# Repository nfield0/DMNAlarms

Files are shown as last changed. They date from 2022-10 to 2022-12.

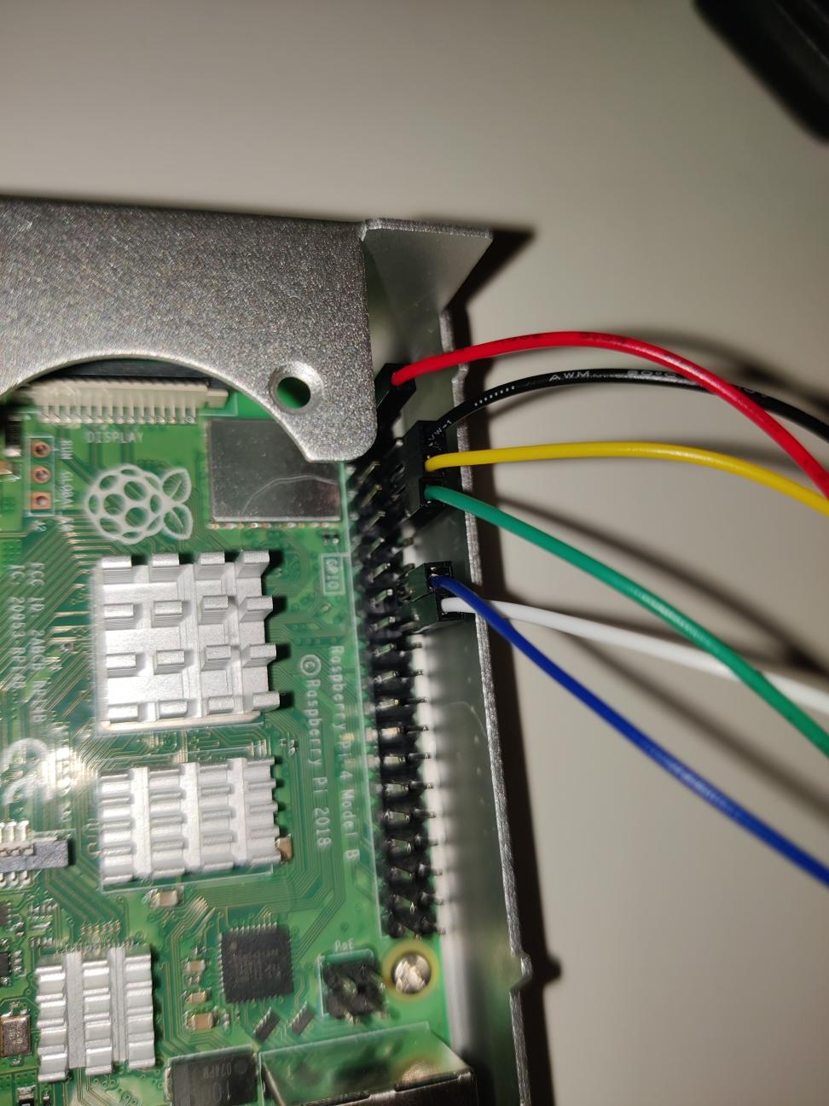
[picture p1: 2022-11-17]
correct_pi_connection_finger_scanner.jpg

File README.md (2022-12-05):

# TRIPL3F LTD
<p align="center">

</p>

## About Us
Our IoT application is an alarm system for single-entry rooms containing valuable documents of some form. After passing fingerprint and facial recognition, the electric strike door lock is unlocked, and entry is granted. There is a door sensor to detect when the door is open and closed. A Database is used to store fingerprint, facial images, date, and time of access. Each stage of the process is accompanied by a speaker, buzzer, and LCD display to guide the user through the system. A flask website is to be used to facilitate a typical front-end user.

### Team Members Roles:
David Campion: Frontend Developer<br />
Michael Flynn: Database Manager & Lead Tester <br />
Nathan Field: Backend Developer <br />
Nikita Fedans: Hardware + Architecture <br />

### Check Out our Website:
qr

shake-and-bake-ricky-bobby

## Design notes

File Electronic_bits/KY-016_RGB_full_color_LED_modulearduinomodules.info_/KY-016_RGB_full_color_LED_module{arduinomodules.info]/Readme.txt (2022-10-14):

//
// ARDUINOMODULES.INFO
// KY-016 RGB full color LED Module
//
// https://arduinomodules.info/ky-016-rgb-full-color-led-module/
//

File includes:
 |
 |- KY-016 RGB full color LED Module.fzpz		//Fritzing Custom Part
 |
 |- Readme.txt						//This file 

Changelog:
  
  Oct-2020
    -Fix Breadboard labels.
    -Fix Schematic labels.
    -Fix PCB holes.
    -Fix PCB size.
    -Fix copper layers order on PCB.

Disclaimer:

KY-016 RGB full color LED Module Fritzing Part is created by arduinomodules.info and published under Creative Commons Attribution-ShareAlike 4.0 International license (https://creativecommons.org/licenses/by-sa/4.0/).
You can use it, share it and/or modify it for any purposes as long as you distribute it under the same license and provide appropriate credit.

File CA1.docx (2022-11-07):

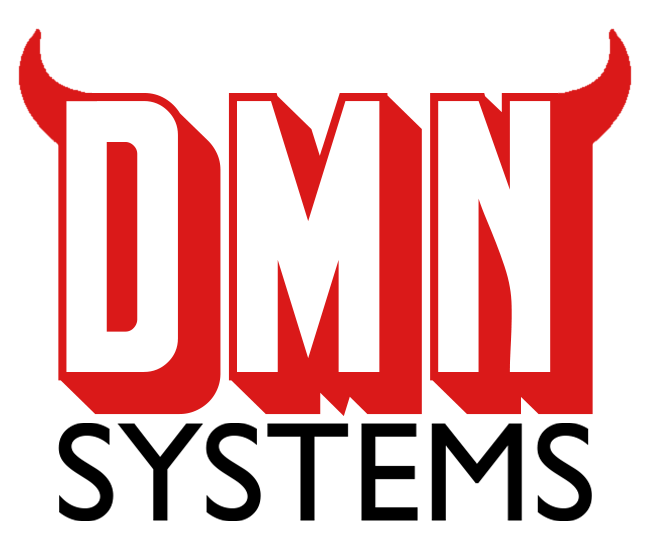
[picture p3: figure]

David Campion, Michael Flynn, Nathan Field & Nikita Fedans

A 2FA Security System for securing single-entry rooms

DMN sYSTEMS

DMN Alarms

DMN Alarms

David Campion, Michael Flynn, Nathan Field & Nikita Fedans

# Introduction

Our IoT application is an alarm system for single-entry rooms containing valuable documents of some form. After passing fingerprint and facial recognition, the electric strike door lock is unlocked, and entry is granted. There is a door sensor to detect when the door is open and closed. A Database is used to store fingerprint, facial images, date, and time of access. Each stage of the process is accompanied by a speaker, buzzer, and LCD display to guide the user through the system. A flask website is to be used to facilitate a typical front-end user.

Team Members Roles:

David Campion: Frontend + UX

Michael Flynn: Database + Testing

Nathan Field: Backend + Testing

Nikita Fedans: Backend + Architecture

# Hardware

## Circuit Diagrams

Circuit:

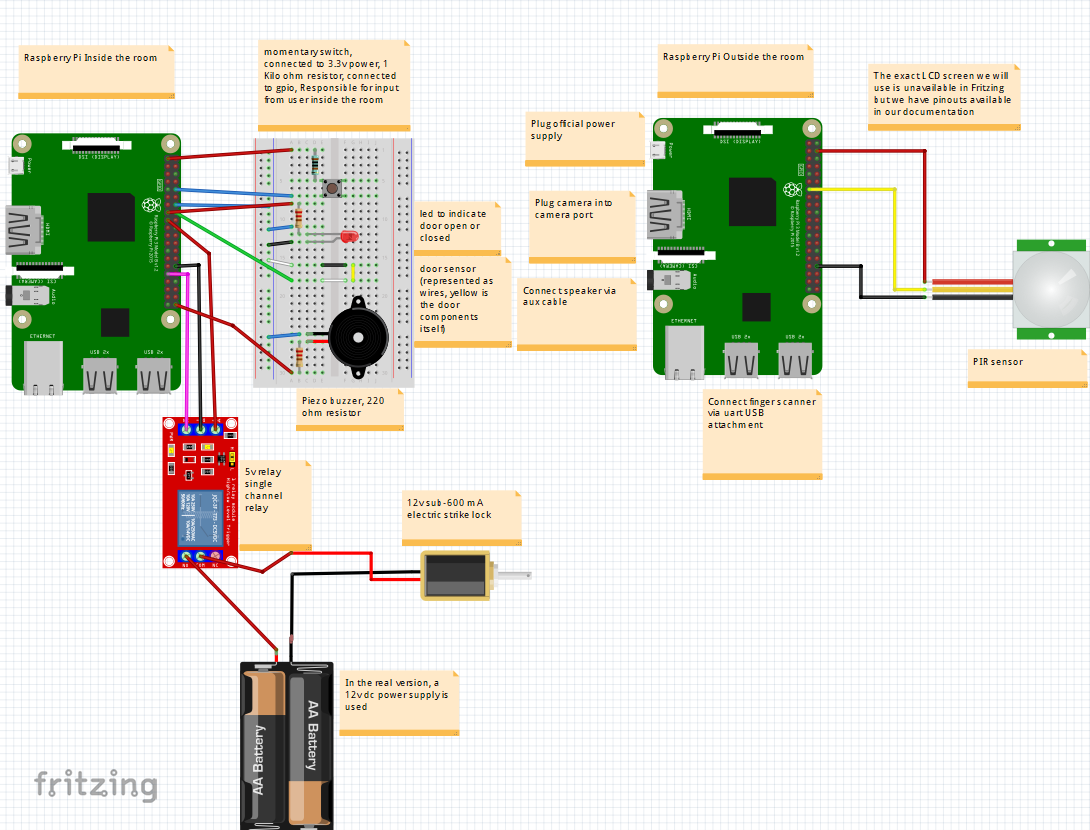
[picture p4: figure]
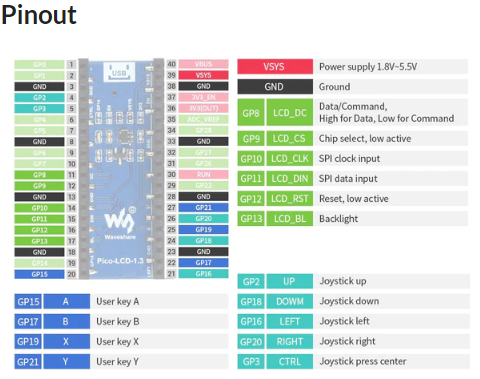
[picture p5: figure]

In Board mode:

Pin 39 of LCD display to Pin 1 of raspberry pi.

Pin 11,12,14,15,16 and 17 of LCD display to Pins 29,31,33,35,37,40 of raspberry pi.

Pin 20, 22, 25, 27 of LCD display to Pins 12, 16, 18 and 22 on raspberry pi.

Connect ground pins as required.

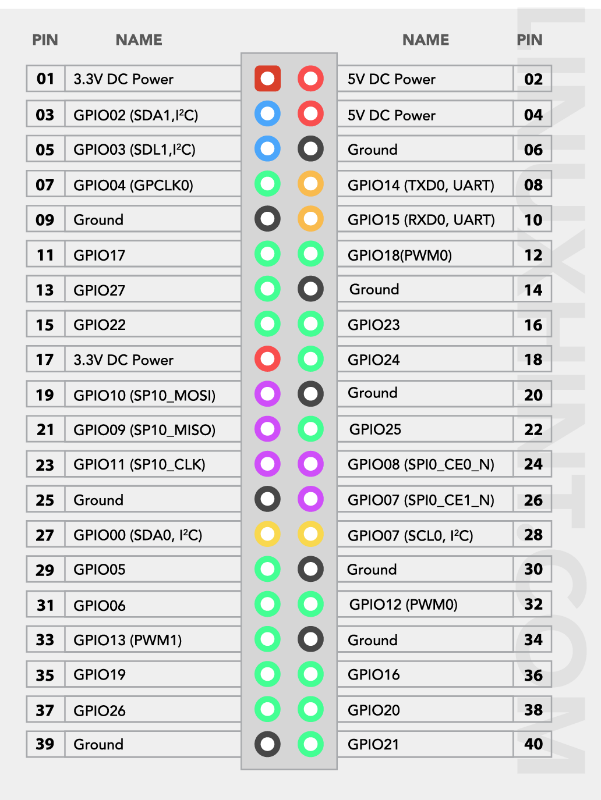
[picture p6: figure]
Raspberry Pi 4 GPIO Pinout

Fritzing circuit commentary:

- Raspberry pi 3 used for diagram. (4 was unavailable)
- Assuming LEDs need 2.2 forward voltage, the resistor needed is a 68.75 ohm one.
- The grounds of all the LEDs may be connected, and then plugged into a single ground pin on the pi, freeing up n-1 ground pins.
- Momentary switch button will be used for sending a signal to raspberry pi.
- No physical pull-down resistor is needed for the switch since an internal pull-down resistor may be assigned to a pin through code.
- LCD display requires a large number of wires and specific part was unavailable in fritzing.
- On the PIR sensor in the fritzing diagram, the VCC, OUT, and GND are inverted compared to the PIR sensors bought from www.pihut.com, so exercise caution when wiring the real thing.

Problems to solve:

- Research how to restrict the “Field of vision” of the pir sensor to only see a specific area.
- Build homemade door sensor.
- Cross-communication of 2 raspberry pi’s for each side of a doorway.

## Hardware Requirements:

Acquired:

1x pir sensor

1x pi camera module (specially made, plugs into special port)

1x buzzer (works with GPIO and 220-ohm resistor)

1x speaker (HDMX speaker, connected to aux, perhaps powered through USB)

Purchases required:

1x fingerprint sensor https://thepihut.com/products/round-all-in-one-capacitive-fingerprint-sensor-d?variant=41540357849283

1x USB to UART https://thepihut.com/products/usb-to-uart-module-micro-mini-type-a-or-type-c?variant=41771472584899

1x 1.3” IPS LCD Display https://thepihut.com/collections/raspberry-pi-screens/products/1-3-ips-lcd-display-module-for-raspberry-pi-pico-240x240

1x electric strike lock https://www.amazon.co.uk/gp/product/B0027VB810?psc=1

1x door switch (commercial or built)

1x button

# Security

## How to secure stored data

securely is one of the most crucial aspects of this project. As we are storing an individual’s personal information such as their name, fingerprint, and image, we must ensure that this sensitive information is therefore protected and not used in a malicious way.

### Securing the system

To ensure the employees personal information is protected we based our security measurements on the STRIDE threat model. The first threat we looked at was spoofing. One of the ways we try to combat spoofing is the user of our multi factor authentication system, this system prevents the user from gaining access to the door if they do not have the authorised fingerprint and facial recognition.

Tampering is another threat that could happen on both front and end, it is crucial to our system that there are different levels of access for each employee, i.e., an admin should be able to change code on the front end or backend, and a backend developer should not be able to add, edit or delete records from the database.

Repudiation was another issue that we were concerned with, if an unauthorised user got into the room and took sensitive documents’ they could deny taking them and we would have no proof to verify that they took it. We decided the best course of action would be to keep a log of which users accessed the room and at what time, this would be stored in a table in our database and will have a relationship with the employee table (employee to access one to many).

Next, we looked at how our system and database could prevent information from being leaked, i.e., how to stop people from finding our database name and password. Based off our lecturer’s guidance we decided to use env variables to prevent unauthorised access, this means that were we to send our code or push it to a site like GitHub then the aforementioned names and passwords will not be visible and there no information leak. We also hashed passwords for extra protection in the event of our database being breached.

Denial of Service attacks were a big worry for us, we therefore did extensive research on the ways in which to prevent these attacks from affecting us, with firewalls being the answer that appeared the most (VPNs and content filtering were other options in preventing these attacks.

In a recent article by Verizon, they claim that 80% of all data breaches happen due to compromised passwords. (https://www.verizon.com/business/resources/reports/dbir/), this worrying statistic got us thinking about how we can come up with more ways to stop users with access to the database and the admin section from having weak passwords, with the simplest solution being to make the user’s password to contain a special, uppercase, lowercase, and numerical character. We also looked at using multi-level authentication such as having a message being sent to your phone with a secure code like how companies such as Google and Amazon do it, however as our project is only small in size and we aren’t expecting attacks in this area, we decided that having a secure password will do for now.

### Privacy

Regarding privacy there was several laws and legislations that we had to consider. As we were using an individual’s personal information, we had to abide by GDPR and right to be forgotten law.

Firstly, will be looking at the GPDR and how we need to adhere to its 7 principles. Due to our usage of an employee’s personal information, it is crucial that we only use this information in a lawful, fair, and transparent manner. In essence we must be open and honest with our employees in how we are using their data as well as not use in inappropriate way such as sending it to third party companies (we are assuming they won’t consent to this)

Another way we must adhere to the GDPR is to only collect data of the employee that is necessary and relevant to what we will be using it for. So, for example we will only need the data such as name, fingerprint, and image and therefore we should be collecting information such as married status or something similar.

A final principle that I think we must adhere to in the GDPR is storage limitation. This law states that data should only be kept for as long as necessary. So, if an employee leaves the company in which the system is being implemented then they must be removed from the database as they information is no longer Is required.

This principle ties in with the second legislation we will be looking which is the Right to be forgotten Act. In essence this act allows a person to have their personal information removed from a company’s database or from the internet. It is important for us as a company to consider this act as if one of the employees leave our company and ask to be removed from the system we must do so.

## Physical security

Our System will have 2 raspberry pi’s mounted to a wall on both sides of the door.

Our Project will be able to control the locking mechanism of the door. In the event there was a power outage, or someone tried to tamper with the system by cutting the power to it, the door will remain locked when power is off. We considered the possibility of an emergency such as a fire, where any one inside may need to escape to safety. Considering this we considered using a backup power source for this project for emergency use only.

# Data Processing and Storage

In our project we will be making use of fingerprint scanners and facial recognition. These sensors will gather employees’ fingerprints and an image of their face, we will store this information in a database.

For our project we had to decide which database would be the most suitable, our options were the traditional MySQL or the more modern database Mongo DB. After careful consideration and deciding what data we will be storing, we opted with MySQL as our database as Mongo does not allow for relationships between the tables.

The first table in our database is the employee_table, in this table is where all the employees’ details such as their first name, surname, email and password as well as their fingerprint and image of their face for the facial recognition of the software, we will also include a Boolean for admin. For the two images the data type will be varchars however the images will be saved as a base64 encoder as it more efficient to transmit the images across the server. As well as this it will also give each employee a unique id to distinguish between each other, this id will function as the tables primary key(pk). Below is the schema and data types for the employee_table.

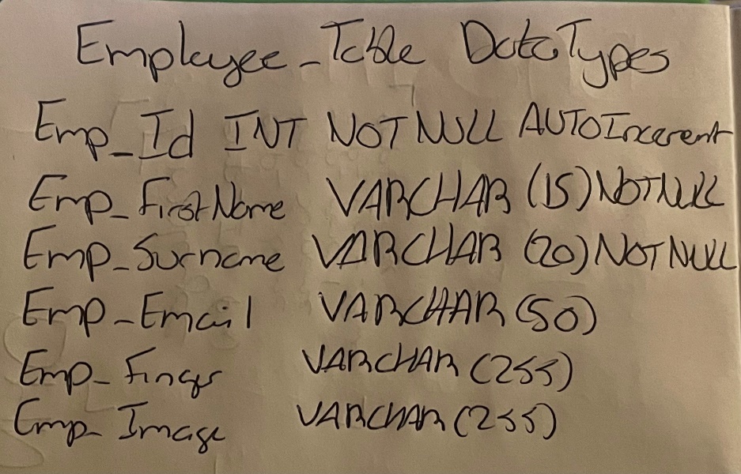
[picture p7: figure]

Theecondd table in our database is the employee_access_table, this table is used the monitor what employee is accessing the door and a what time they are accessed the door at. This table is a good way to improve the systems security and it limits the risk of repudiation (discussed in the security section of this documentation) as it means people can’t lie about whether they were or were not in the room. This table will contain a unique access id (pk) as well as the employees id (foreign key from the employee table) and an access time. Below is the schema for the employee_access_table

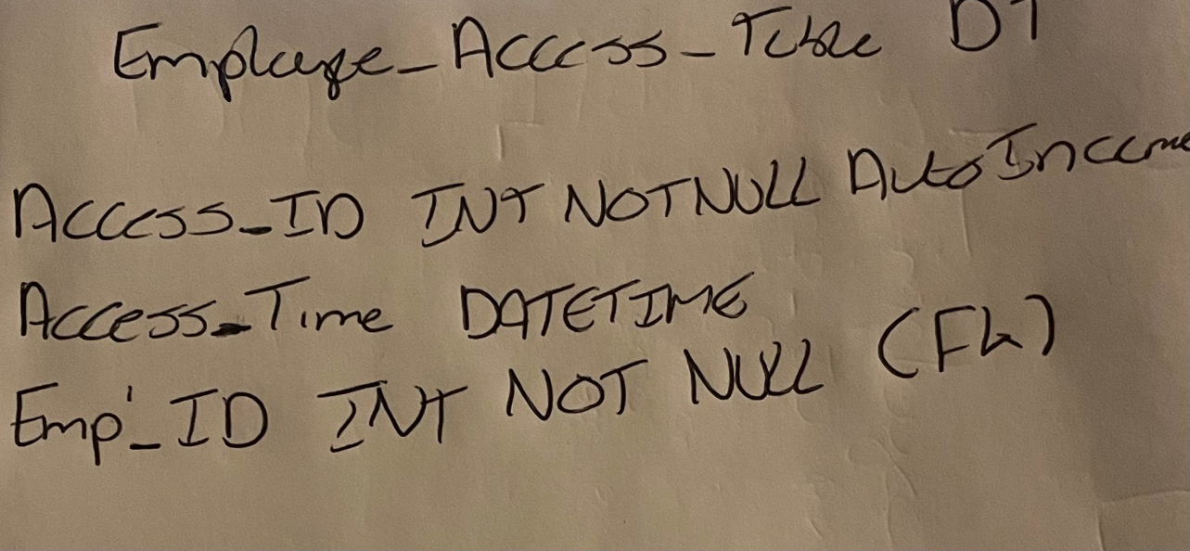
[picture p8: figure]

So as briefly mentioned we will be relating the two tables in our database, the relationship between these two tables is a one to many relationship (one employee can have many accesses to the door but the door can only have one access at any given time). Below is a sketch of the relationship between these two tables (note the admin Boolean is not in the diagram).

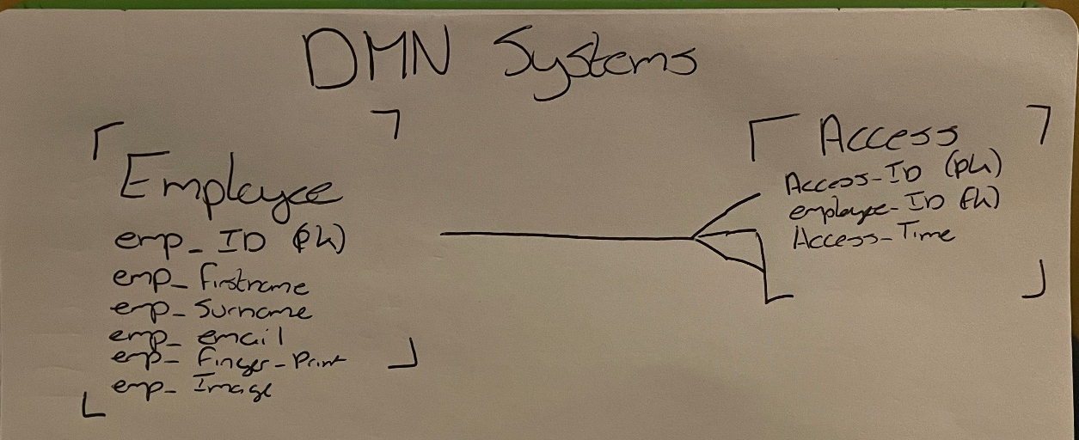
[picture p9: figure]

## Queries

We will also be using queries and views in our database to help us search for certain records in the database that combine both tables, while at the moment our queries are limited the plan is to expand on them as the database get bigger, below is our first few basic queries for the database

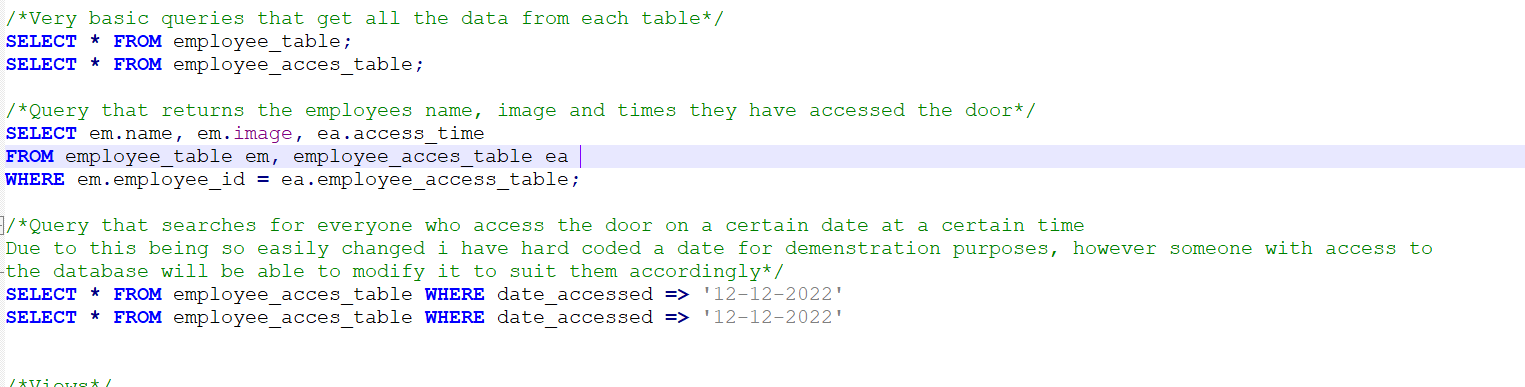
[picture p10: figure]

We will also be making use of views in our database to let other workers in the system search for certain records without risk of them editing or tampering with the records in anyway.

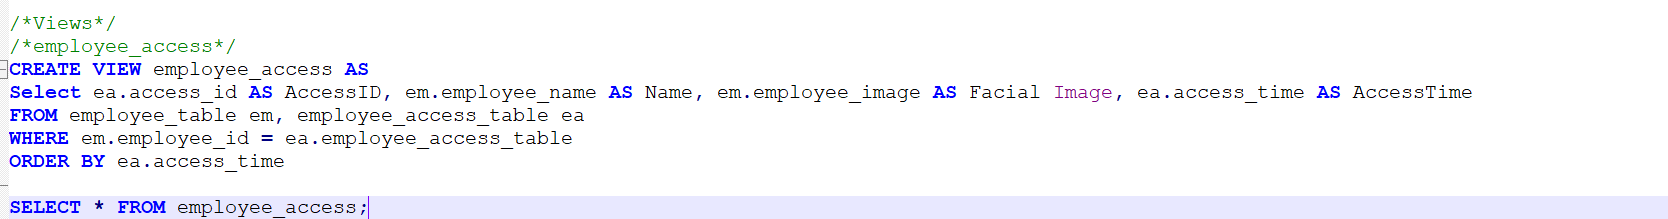
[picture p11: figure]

We also considered the possibility of using indexes for databases as well to allow our admins to quicky find employees by their last name. However, as our database is not the largest (yet) this index will probably not get much use as a simple SELECT emp_lastname FROM employee_table will get the results at the same speeds.

A final note on the database and something that will be discussed more in security, is securing the database to prevent it from hackers or SQL Injections. In order to prevent the latter, we will be making use of SQL parameters, these parameters will also hide the database structure from potential hackers. To do this in python you use connection.cursor(prepared = TRUE)

# The UI, User and User Testing

## The UI

(Provided by David Campion)

The Flask website design can be found here: https://www.figma.com/file/B5OAyUPiC5Eks1s3S356iJ/DMN-Systems-Prototype?node-id=0%3A1

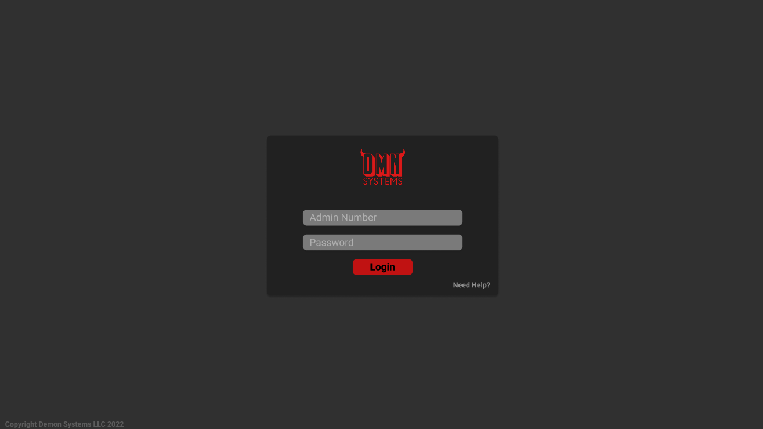
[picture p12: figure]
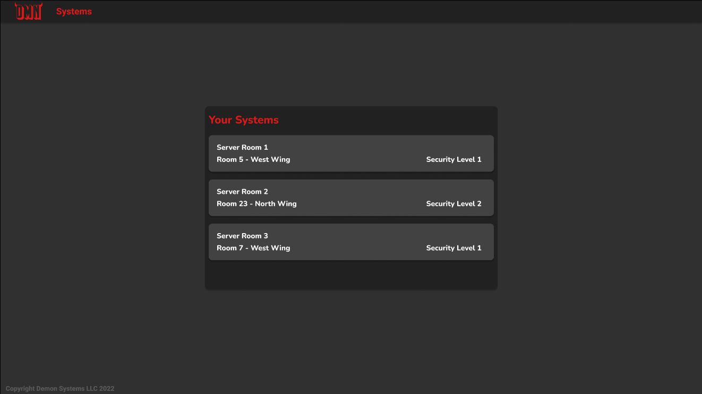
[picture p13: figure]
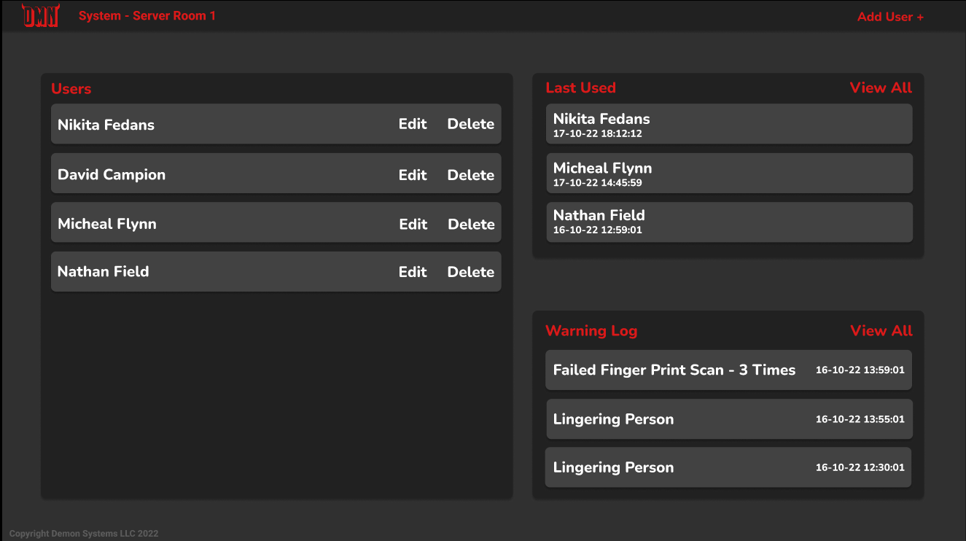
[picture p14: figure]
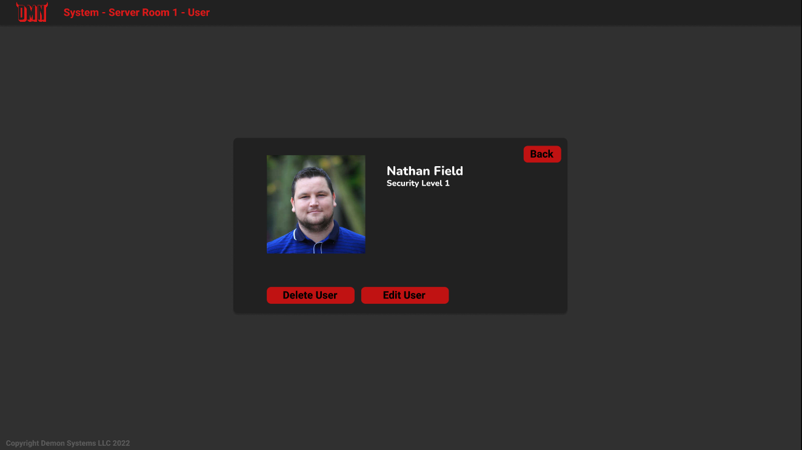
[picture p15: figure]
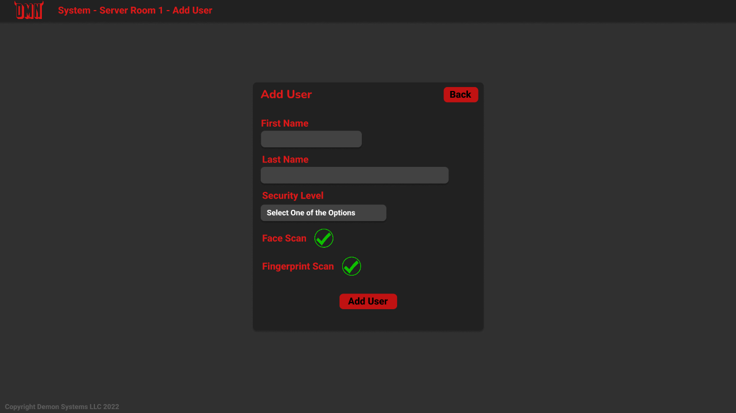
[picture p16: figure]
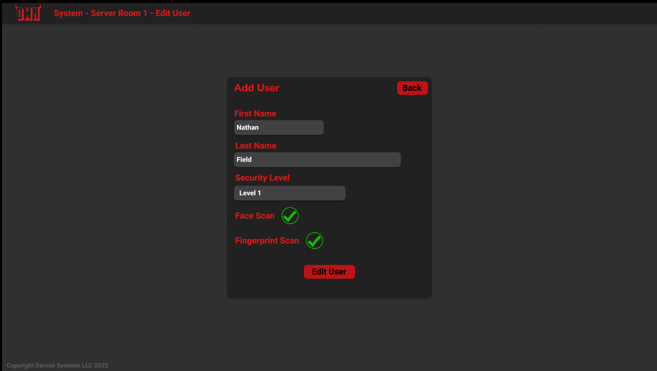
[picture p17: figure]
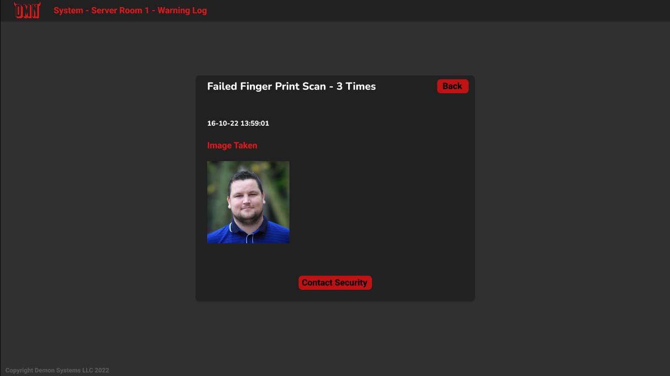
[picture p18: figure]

LCD display prototype here:

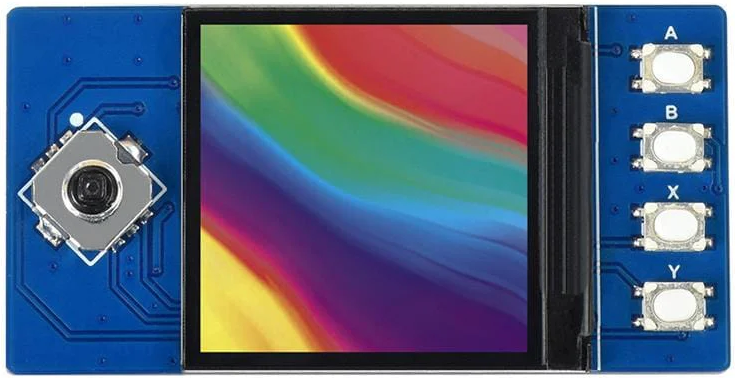
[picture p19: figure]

## The User

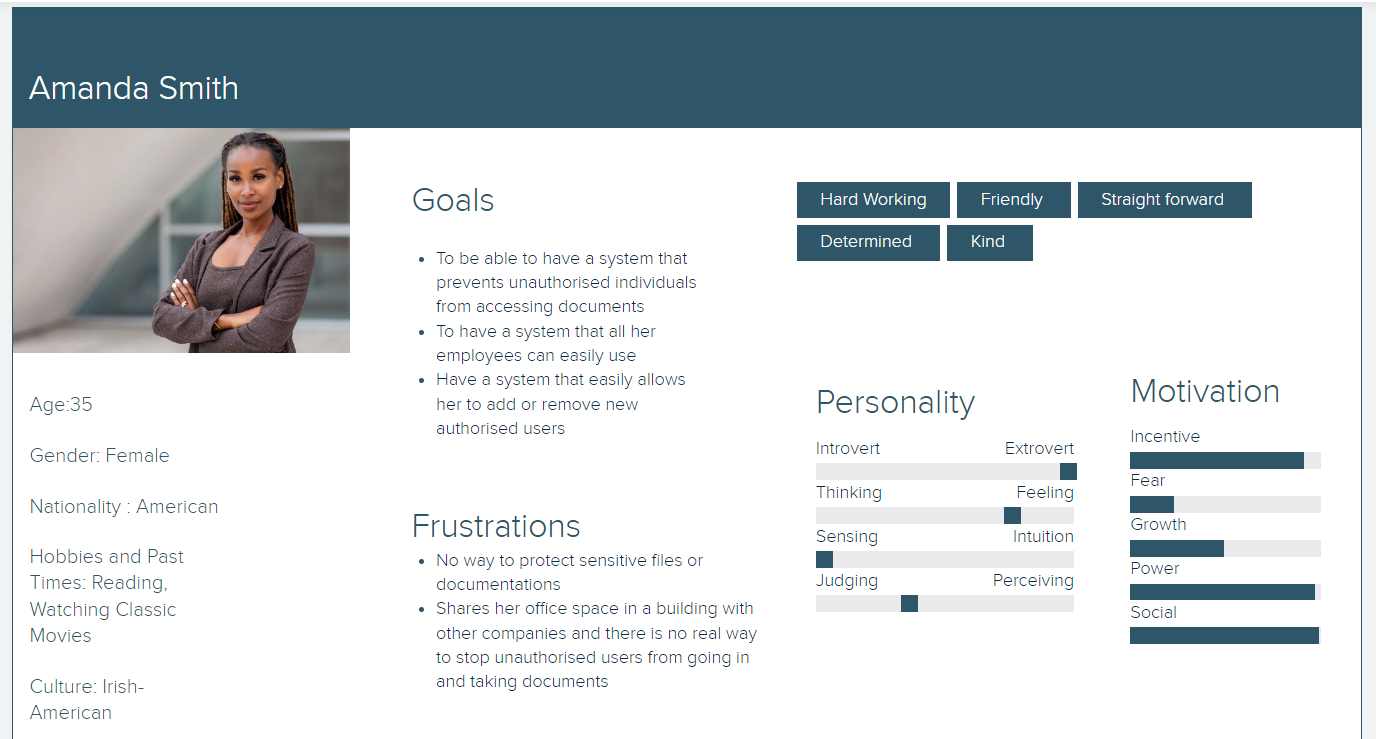
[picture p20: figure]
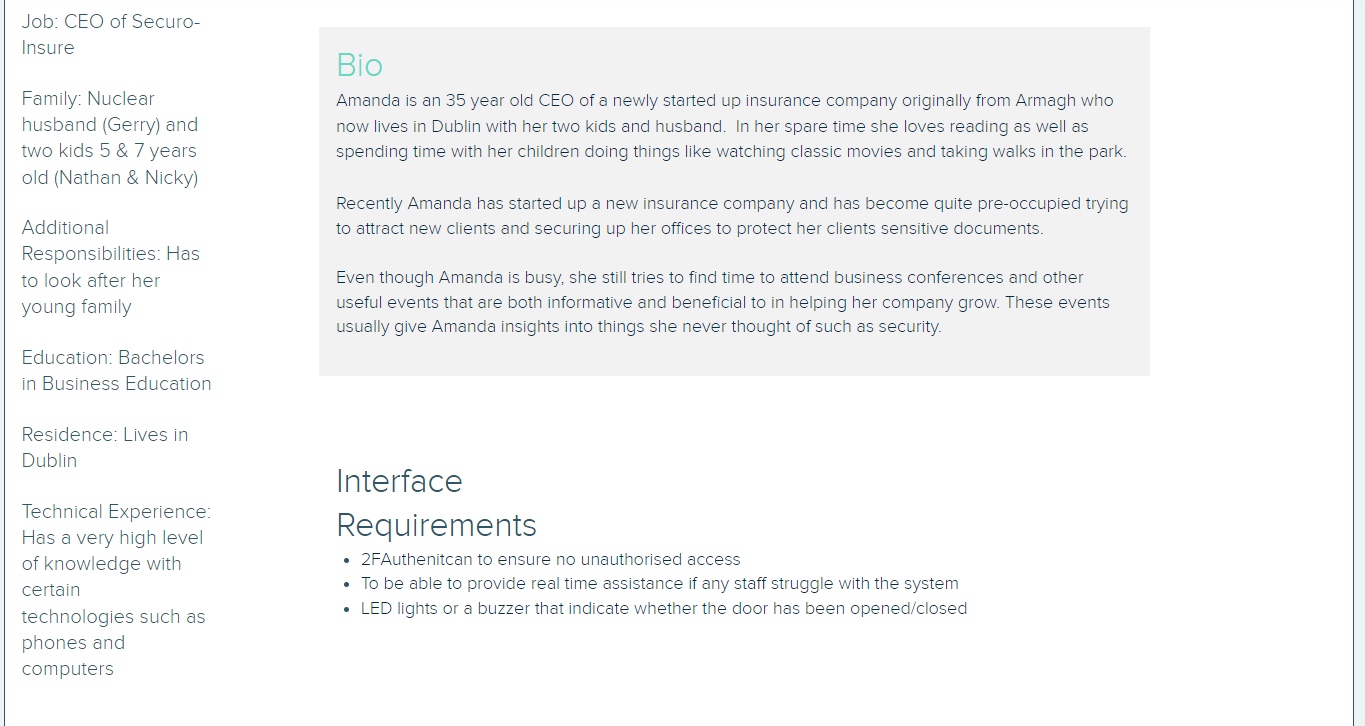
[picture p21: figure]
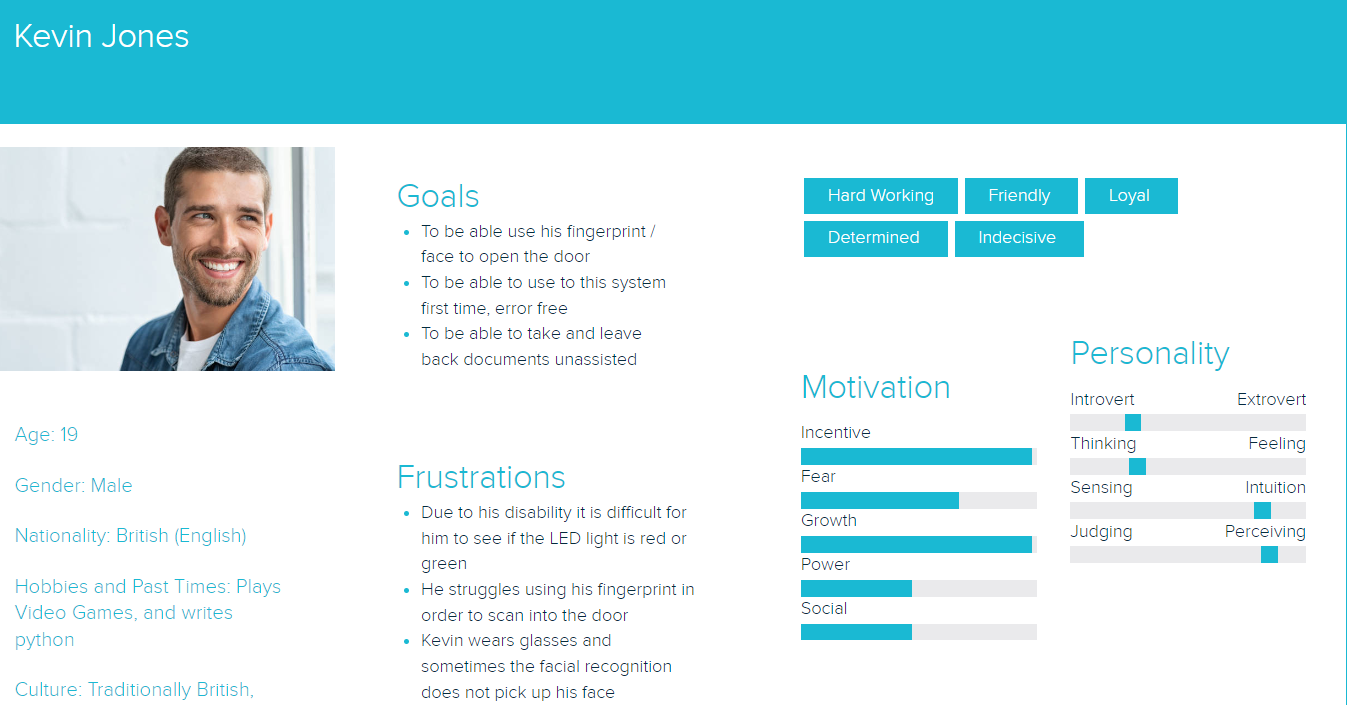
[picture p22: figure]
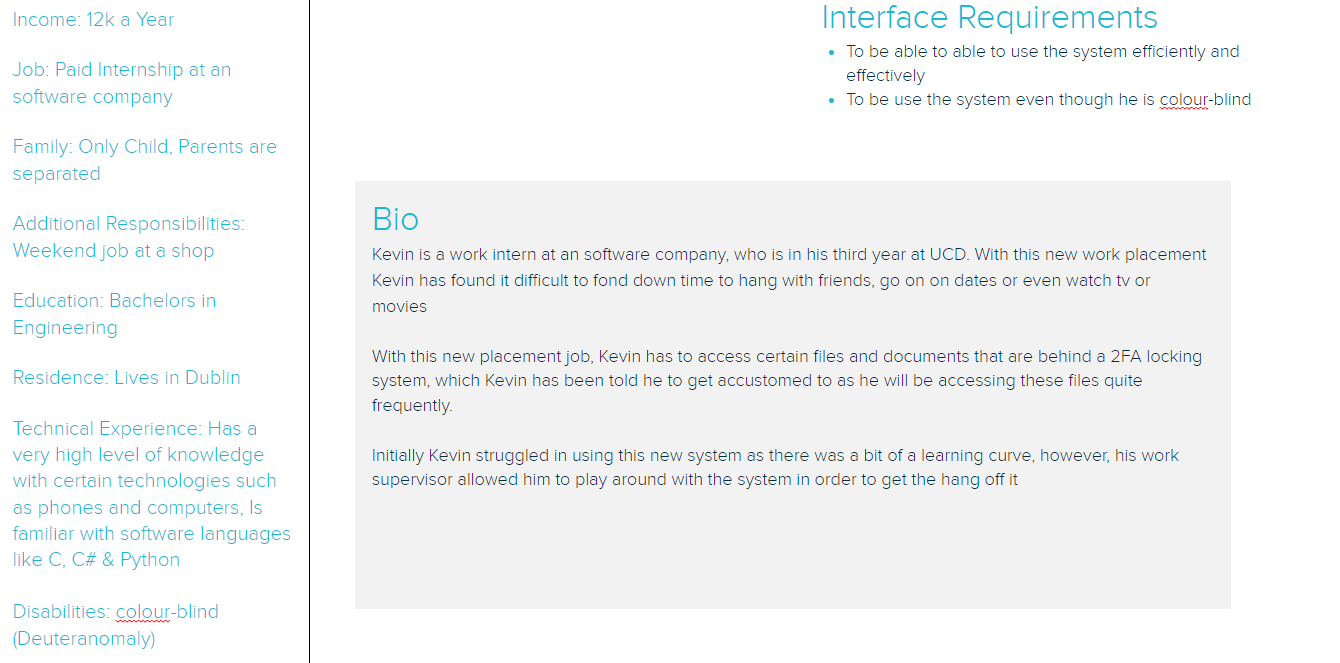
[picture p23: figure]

## User Testing

### User Interaction Flowcharts

1) Entering from the outside, available here: https://www.canva.com/design/DAFPBEU1cgY/_33aS6_us3ViciJL2B3JKQ/edit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
2) Exiting from the inside, available here: https://www.canva.com/design/DAFPB6XopUE/RulFr5eydPou51SDKPa_SQ/edit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

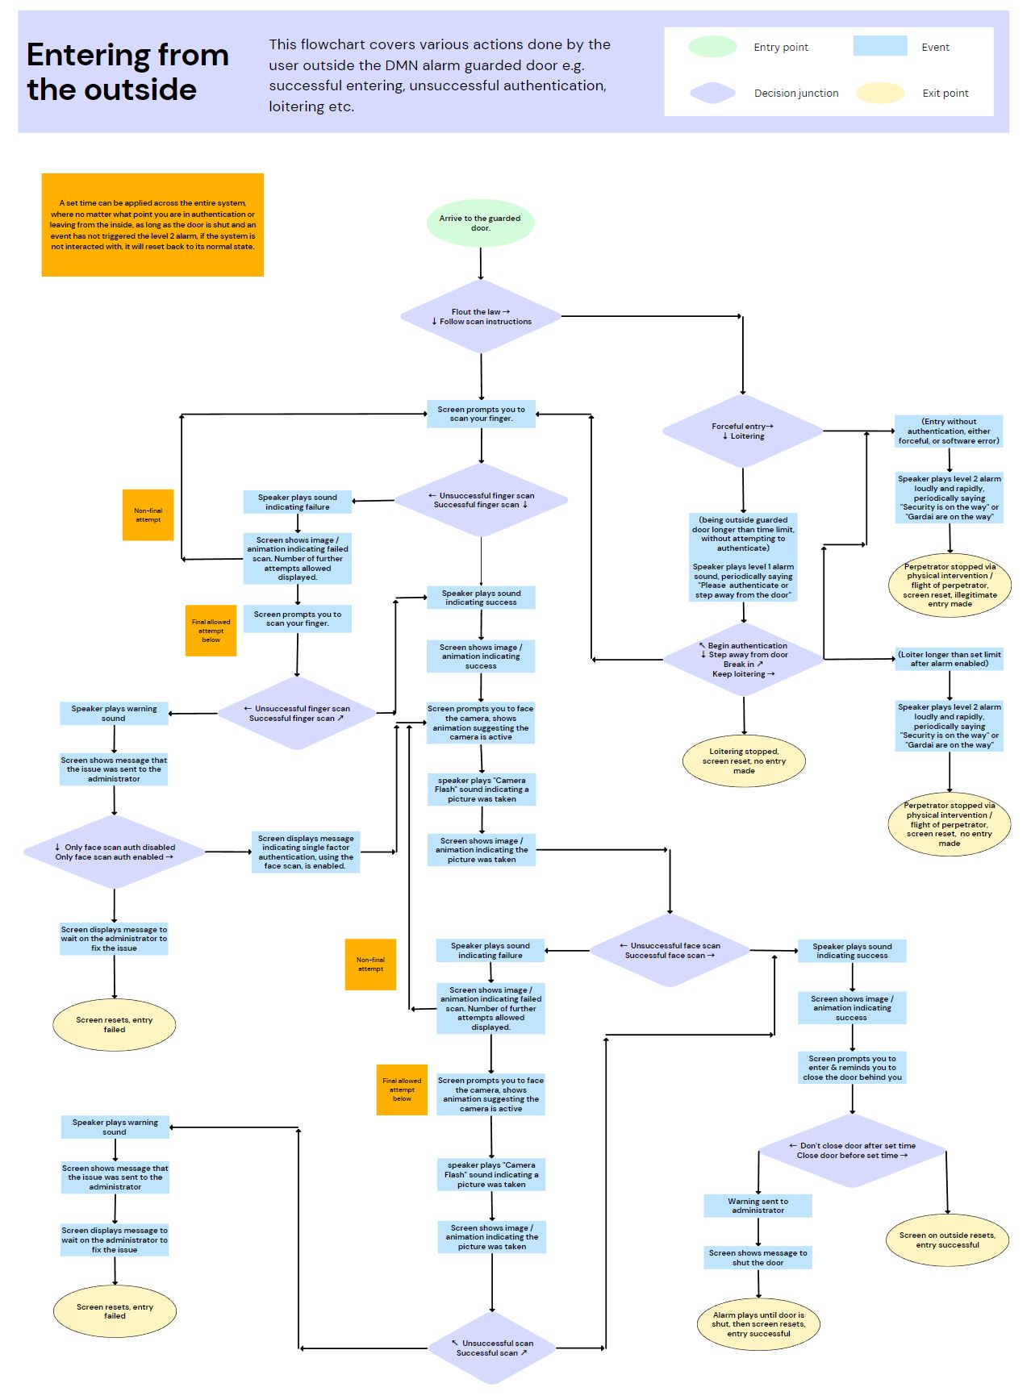
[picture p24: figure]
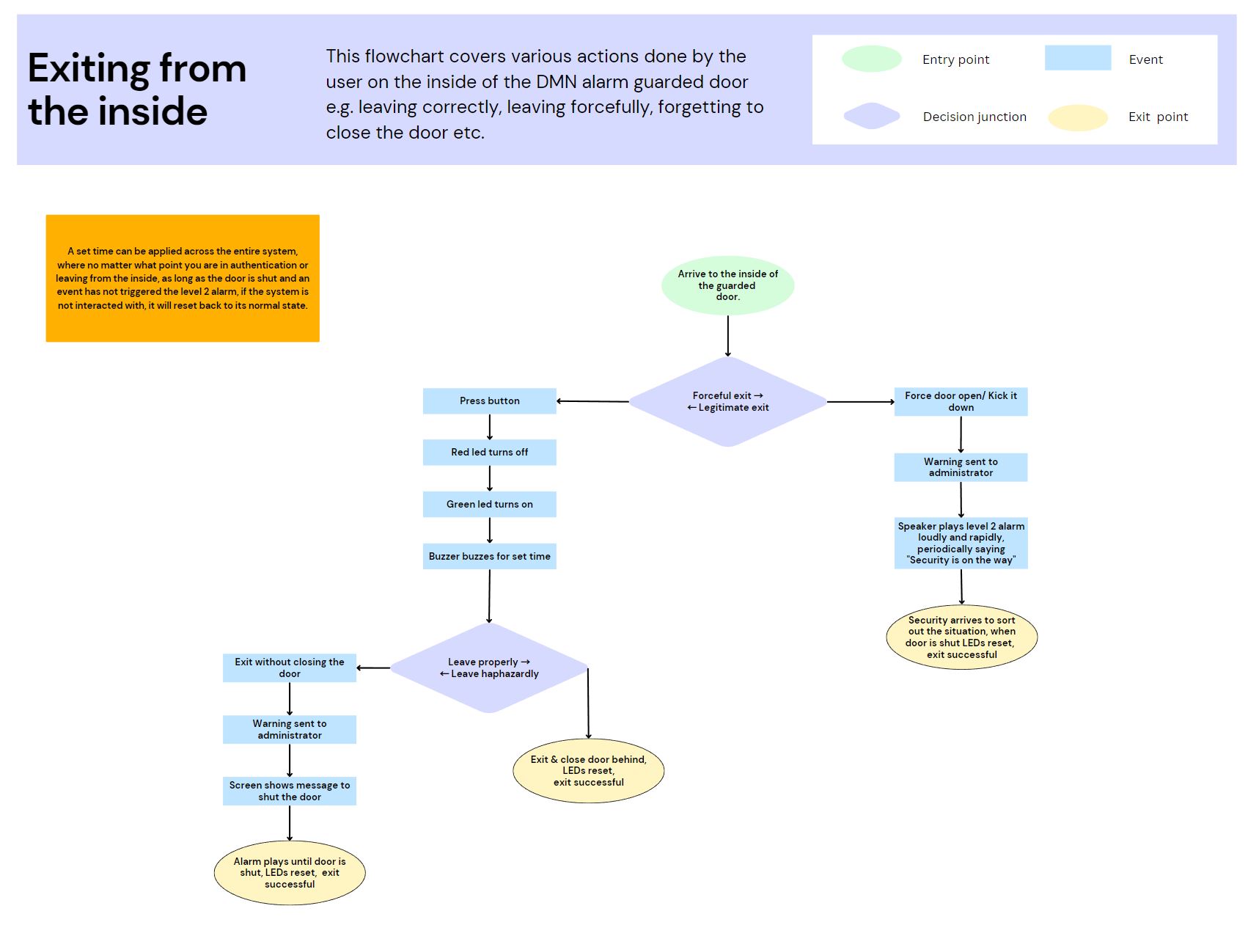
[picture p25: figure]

### Target and Success

This device is mainly for commercial premises with single-entry rooms containing valuable goods of some kind.

This project will be considered successful if it successfully allows authorized users to gain entry to the room and deny unauthorized entry to the room. From an administrator’s perspective, it will be successful if an administrator can add a new employee to the system without the need for assistance.

# Bibliography

Alex Hewko. (2021). STRIDE Threat Modeling: What You Need to Know. [Online]. Software Secured. Last Updated: 2022. Available at: https://www.softwaresecured.com/stride-threat-modeling/ [Accessed 19 October 2022].

Data Protection Commission. (2022). Principles of the Data Protection. [Online]. Data Protection. Last Updated: 2022. Available at: https://www.dataprotection.ie/en/individuals/data-protection-basics/principles-data-protection [Accessed 19th October 2022].

IBM. (2021). MySQL vs. MongoDB: What’s the Difference?. [Online]. IBM. Last Updated: 2022. Available at: https://www.ibm.com/cloud/blog/mysql-vs-mongodb [Accessed 22 October 2022].

Information Commissioner's Office. (2022). Right to Erasure ICO. [Online]. ICO. Last Updated: 2022. Available at: https://ico.org.uk/for-organisations/guide-to-data-protection/guide-to-the-general-data-protection-r [Accessed 19th October 2022].

Paul Reubens . (2021). Database Security: 7 Best Practices & Tips. [Online]. eSecurity Planet. Last Updated: 2022. Available at: https://www.esecurityplanet.com/networks/database-security-best-practices/ [Accessed 19th October 2022].

TripWire. (2021). 10 Database Security Best Practices You Should Know. [Online]. TripWire. Last Updated: 2022. Available at: https://www.dataprotection.ie/en/individuals/data-protection-basics/principles-data-protection [Accessed 18th October 2022].

# Versioning

Version 1: Document Creation – 07/10/2022

Version 2: Introduction, Table of Contents and Hardware requirements – 08/10/2022

Version 3: Added Cover Page – 10/10/2022

Version 4: Updated team roles, hardware requirements, STRIDE, User personas and circuit diagram – 14/10/2022

Version 5: Added user interaction Flowchart Diagrams – 14/10/2022

Version 6: Added Database Processing, Storage, Privacy and Security – 19/10/2022

Version 7: Added Flask Website Prototype, Proofreading, developed physical security, Target and Success Criteria – 20/10/2022

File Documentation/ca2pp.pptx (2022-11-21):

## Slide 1

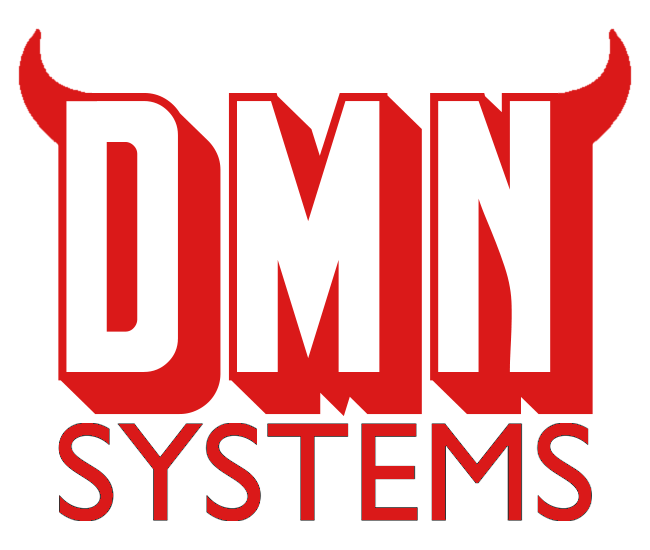
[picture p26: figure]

David Campion – Michael Flynn – Nathan Field – Nikita Fedans

## Housekeeping

- Roles

- Nikita Fedans: Hardware & Backend
- Nathan Field: Front and back end
- Michael Flynn: Database and frontend
- David Campion: frontend & CSS

- Tasks

- Assembling & coding for the lock, fingerprint sensor and opening button
- Worked on the Frontend and linked the fingerprint sensor to the website
- Created the database, hosted it, and worked on the frontend
- Styling of web page

## Progress

- Completed: website and database hosted. Lock wired correctly and working. Fingerprint able to register new users and verify user’s fingerprints. Fingerprint scans put into database and visible on log, on website. https enabled.
- Left to do: write all face recognition code. Be able to add/delete a fingerprint to a user record in the database through the website. Connect the display for user feedback. Clean up website styling and put together secure boxes to mount sensors.

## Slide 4

Persona 1

Persona 2


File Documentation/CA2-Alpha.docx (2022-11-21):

CA2 -DMN SYSTEMS ALPHA RELEASE

David, Michael Nathan & Nikita

# System Architecture

# Beta Prototype

## Hardware

## Web server & UI

## Security

## Database

## Data processing

# Deploy to AWS

## Custom Domain

## HTTPS

## Available after submission

# PubNub

## Access Manger

## SSL

## Communication

# Security

## Device

## Communication Channels

## Database

## Webserver

## Data in Flow

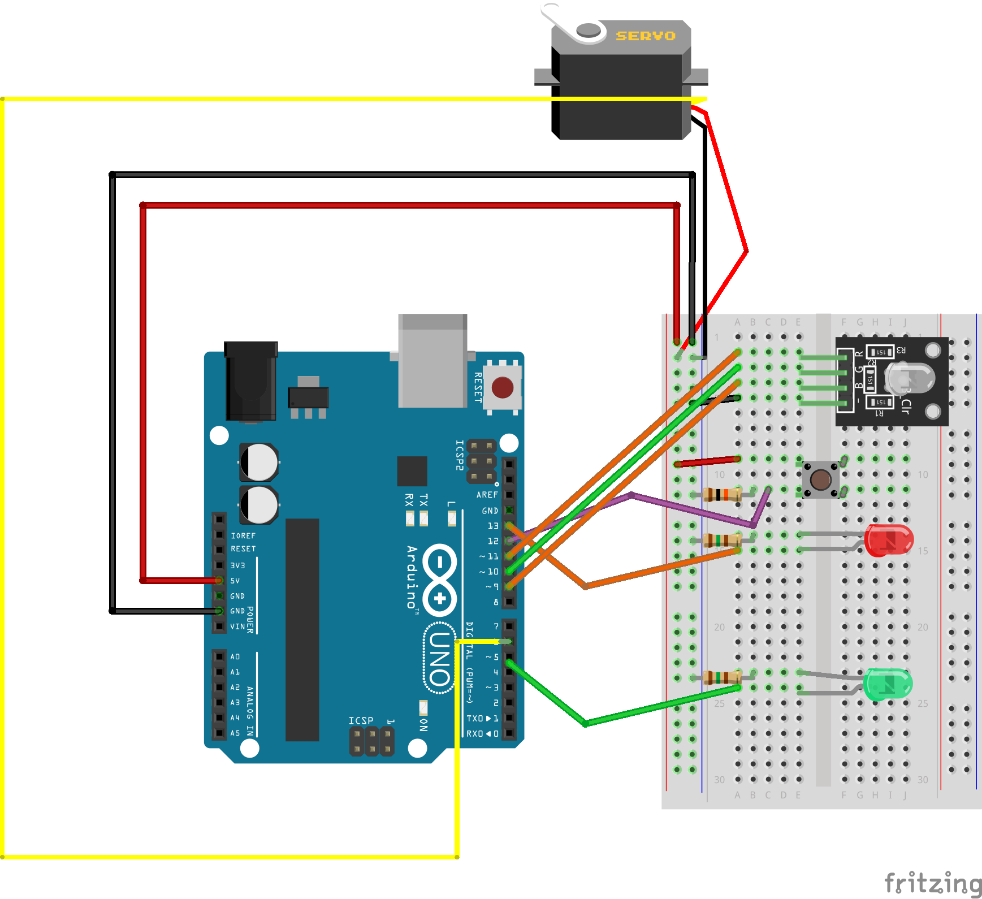
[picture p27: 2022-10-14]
Electronic_bits/first circuit.png

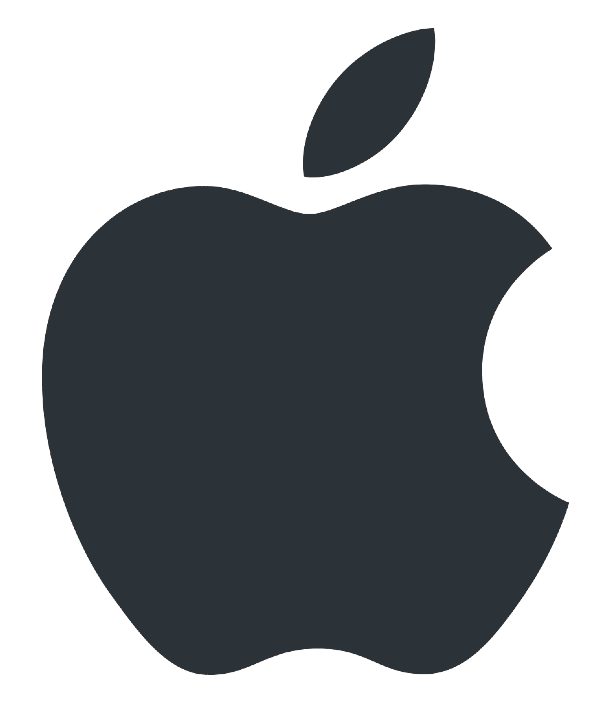
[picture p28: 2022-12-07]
static/images/apple.png

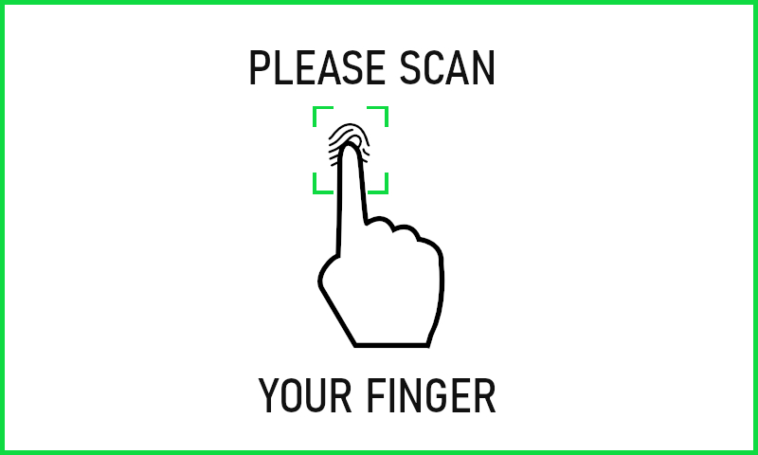
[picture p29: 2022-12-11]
screen_img.jpg

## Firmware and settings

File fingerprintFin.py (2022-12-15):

#!/usr/bin/env python3.5
# -*- coding:utf-8 -*-

import serial
import time
import threading
import sys
import RPi.GPIO as GPIO

from pubnub.callbacks import SubscribeCallback
from pubnub.enums import PNStatusCategory, PNOperationType
from pubnub.pnconfiguration import PNConfiguration
from pubnub.pubnub import PubNub

myChannel = "dmn-channel"
sensorList = ["finger_scanner, finger_scanner_new"]
data = {}

pnconfig = PNConfiguration()

pnconfig.subscribe_key = 'sub-c-5efa4cb5-6f01-42ea-a6ac-98b3dccd764a'
pnconfig.publish_key = 'pub-c-6df66f48-e71d-41ea-a2a7-d696bda5a561'
pnconfig.uuid = 'exterior-pi'
pubnub = PubNub(pnconfig)

TRUE = 1
FALSE = 0

# Basic response message definition
ACK_SUCCESS = 0
ACK_FAIL = 1
ACK_FULL = 4
ACK_NO_USER = 5
ACK_TIMEOUT = 8
ACK_GO_OUT = 15  # The center of the fingerprint is out of alignment with sensor

# User information definition
ACK_ALL_USER = 0
ACK_GUEST_USER = 1
ACK_NORMAL_USER = 2
ACK_MASTER_USER = 3

USER_MAX_CNT = 1000  # Maximum fingerprint number

# Command definition
CMD_HEAD = 245
CMD_TAIL = 245
CMD_ADD_1 = 1
CMD_ADD_2 = 2
CMD_ADD_3 = 3
CMD_MATCH = 12
CMD_DEL = 4
CMD_DEL_ALL = 5
CMD_USER_COUNT = 9
CMD_SET_OR_QUERY_COMPARISON_LEVEL = 40
CMD_SLEEP_MODE = 44
CMD_TIMEOUT = 46

CMD_FINGER_DETECTED = 20  # NOT FOUND IN DOCUMENTATION

Finger_WAKE_Pin = 23
Finger_RST_Pin = 24

GPIO.setmode(GPIO.BCM)
GPIO.setwarnings(False)
GPIO.setup(Finger_WAKE_Pin, GPIO.IN)
GPIO.setup(Finger_RST_Pin, GPIO.OUT)
GPIO.setup(Finger_RST_Pin, GPIO.OUT)
GPIO.output(Finger_RST_Pin, GPIO.HIGH)

g_rx_buf = []  # RXD
latest_scanned_id = 0
PC_Command_RxBuf = []  # Figure OUT
Finger_SleepFlag = 0

# rLock = threading.RLock()     Was here before i did anything
ser = serial.Serial(port="/dev/ttyS0", baudrate=19200, parity=serial.PARITY_NONE,
                    stopbits=serial.STOPBITS_ONE, write_timeout=None, timeout=None, bytesize=8)


# Set up serial connection, cts and rts also available params


# ***************************************************************************
# @brief    send a command, and wait for the response of module
# ***************************************************************************/

def TxAndRxCmd(command_buf, rx_bytes_need, timeout):  # [0x28, 0, level, 0, 0] , 8, 0.1
    global g_rx_buf
    CheckSum = 0
    tx_buf = []
    tx = b''

    print("COMMAND BUFFER: ", command_buf)

    tx_buf.append(CMD_HEAD)  # [0xF5]
    for int_val in command_buf:
        tx_buf.append(int_val)
        CheckSum ^= int_val

    print("CHECKSUM: ", CheckSum)
    tx_buf.append(CheckSum)
    tx_buf.append(CMD_TAIL)

    for i in tx_buf:
        print(i)
        tx += i.to_bytes(1, "big")

    ser.reset_input_buffer()  # Old flushInput() is deprecated

    print("TYPE OF TX NOW!!!: ", type(tx))
    print("TX NOW: ", tx)

    print("Byte String TX: : ", tx)
    wrtn = ser.write(tx)

    print("Returned from write(): " + str(wrtn))

    g_rx_buf = []
    time_before = time.time()
    time_after = time.time()
    while time_after - time_before < timeout and len(g_rx_buf) < rx_bytes_need:  # Waiting for response
        bytes_can_recv = ser.in_waiting  # Old method deprecated
        if bytes_can_recv != 0:
            g_rx_buf += ser.read(bytes_can_recv)
        time_after = time.time()

    if len(g_rx_buf) != rx_bytes_need:
        print("RET 1")
        print("Length of g_rx_buf: " + str(len(g_rx_buf)))
        print(g_rx_buf)
        return ACK_TIMEOUT
    if g_rx_buf[0] != CMD_HEAD:
        print(g_rx_buf[0])
        print("RET 2")
        return ACK_FAIL
    if g_rx_buf[rx_bytes_need - 1] != CMD_TAIL:
        print("RET 3")
        return ACK_FAIL
    if g_rx_buf[1] != tx_buf[1]:
        print(g_rx_buf[1])
        print(tx_buf[1])
        print("RET 4")
        return ACK_FAIL  # STOPPED HERE#################################

    CheckSum = 0
    for index, byte in enumerate(g_rx_buf):
        if index == 0:
            continue
        if index == 6:
            if CheckSum != byte:
                print("RET 5")
                return ACK_FAIL
        CheckSum ^= byte
    print("RET 6")
    return ACK_SUCCESS


# ***************************************************************************
# @brief    Get Compare Level
# ***************************************************************************/
def GetCompareLevel():
    global g_rx_buf
    command_buf = [CMD_SET_OR_QUERY_COMPARISON_LEVEL, 0, 0, 1, 0]
    r = TxAndRxCmd(command_buf, 8, 0.1)
    print(g_rx_buf)
    print("*******************************************")
    if r == ACK_TIMEOUT:
        return ACK_TIMEOUT
    if r == ACK_SUCCESS and g_rx_buf[4] == ACK_SUCCESS:
        return g_rx_buf[3]
    else:
        return 0xFF


def SetCompareLevel(level):
    global g_rx_buf
    command_buf = [CMD_SET_OR_QUERY_COMPARISON_LEVEL, 0, level, 0, 0]
    r = TxAndRxCmd(command_buf, 8, 0.1)

    if r == ACK_TIMEOUT:
        return ACK_TIMEOUT
    if r == ACK_SUCCESS and g_rx_buf[4] == ACK_SUCCESS:
        return g_rx_buf[3]
    else:
        return 0xFF


def GetUserCount():
    global g_rx_buf
    command_buf = [CMD_USER_COUNT, 0, 0, 0, 0]
    r = TxAndRxCmd(command_buf, 8, 0.1)
    if r == ACK_TIMEOUT:
        return ACK_TIMEOUT
    if r == ACK_SUCCESS and g_rx_buf[4] == ACK_SUCCESS:
        return g_rx_buf[3]
    else:
        return 0xFF


# ***************************************************************************
# @brief   Get the time that fingerprint collection wait timeout
# ***************************************************************************/
def GetTimeOut():
    global g_rx_buf
    command_buf = [CMD_TIMEOUT, 0, 0, 1, 0]
    r = TxAndRxCmd(command_buf, 8, 0.1)
    if r == ACK_TIMEOUT:
        return ACK_TIMEOUT
    if r == ACK_SUCCESS and g_rx_buf[4] == ACK_SUCCESS:
        return g_rx_buf[3]
    else:
        return 0xFF


# ***************************************************************************
# @brief    Register fingerprint
# ***************************************************************************/

#def run_it():
    #Analysis_PC_Command("CMD5")


# def AddUser():
#     print("ADD ADD ADD ADD ADD ADD ADD ADD ADD ADD ADD ADD ADD")
#
#     global g_rx_buf
#     r = GetUserCount()
#     # if r >= USER_MAX_CNT:
#     # return ACK_FULL
#     print("ttttttttttttttttttttttttt", g_rx_buf[4])
#     count = 0
#     return_var = ""
#
#     #while r != ACK_SUCCESS and g_rx_buf[4] != ACK_SUCCESS or count < 5:
#     while r != ACK_SUCCESS or count < 5:
#         command_buf = [CMD_ADD_1, 0, r + 1, 3, 0]
#         r = TxAndRxCmd(command_buf, 8, 6)
#         print(g_rx_buf)
#         print("ADD ADD ADD ADD ADD ADD ADD ADD ADD ADD ADD ADD ADD")
#         print("****************************")
#         if r == ACK_TIMEOUT:
#             return_var = ACK_TIMEOUT
#         if r == ACK_SUCCESS and g_rx_buf[4] == ACK_SUCCESS:
#             command_buf[0] = CMD_ADD_3
#             r = TxAndRxCmd(command_buf, 8, 6)
#             latest_scanned_id = g_rx_buf[3]
#             nvar = r + 1
#             publish(myChannel, {"finger_scanner_new": GetUserCount()})
#             print(g_rx_buf)
#             time.sleep(2)
#             # Analysis_PC_Command("CMD5")
#             # run_it()
#             # print("Change to cmd5")
#             if r == ACK_TIMEOUT:
#                 return_var = ACK_TIMEOUT
#             if r == ACK_SUCCESS and g_rx_buf[4] == ACK_SUCCESS:
#                 return_var = ACK_SUCCESS
#             else:
#                 return_var = ACK_FAIL
#         else:
#             return_var = ACK_FAIL
#         count += 1
#
#     print("RETURNINGGGGGGGGGGGGGGGGGG: ", return_var)
#     return return_var


def AddUser():
    global g_rx_buf
    r = GetUserCount()
    if r >= USER_MAX_CNT:
        return ACK_FULL

    command_buf = [CMD_ADD_1, 0, r + 1, 3, 0]
    print(g_rx_buf)
    r = TxAndRxCmd(command_buf, 8, 6)
    if r == ACK_TIMEOUT:
        return ACK_TIMEOUT
    if r == ACK_SUCCESS and g_rx_buf[4] == ACK_SUCCESS:
        command_buf[0] = CMD_ADD_3
        r = TxAndRxCmd(command_buf, 8, 6)
        print(g_rx_buf)
        publish(myChannel, {"finger_scanner_new": GetUserCount()})
        time.sleep(2)
        if r == ACK_TIMEOUT:
            return ACK_TIMEOUT
        if r == ACK_SUCCESS and g_rx_buf[4] == ACK_SUCCESS:
            return ACK_SUCCESS
        else:
            return ACK_FAIL
    else:
        return ACK_FAIL


# ***************************************************************************
# @brief    Clear fingerprints
# ***************************************************************************/
def ClearAllUser():
    print("gagagagagagagagagaggaaggagagagag")
    global g_rx_buf
    command_buf = [CMD_DEL_ALL, 0, 0, 0, 0]
    r = TxAndRxCmd(command_buf, 8, 5)
    if r == ACK_TIMEOUT:
        return ACK_TIMEOUT
    if r == ACK_SUCCESS and g_rx_buf[4] == ACK_SUCCESS:
        # Analysis_PC_Command("CMD5")
        # print("Change to cmd5")
        publish(myChannel, {"finger_prints_removed": 1})
        return ACK_SUCCESS
    else:
        return ACK_FAIL


# ***************************************************************************
# @brief    Check if user ID is between 1 and 3
# ***************************************************************************/
def IsMasterUser(user_id):
    if user_id == 1 or user_id == 2 or user_id == 3:
        return TRUE
    else:
        return FALSE


# ***************************************************************************
# @brief    Fingerprint matching
# ***************************************************************************/
def VerifyUser():
    global g_rx_buf
    global latest_scanned_id
    command_buf = [CMD_MATCH, 0, 0, 0, 0]
    r = TxAndRxCmd(command_buf, 8, 5)
    print(g_rx_buf)
    print("****************************")
    if r == ACK_TIMEOUT:
        return ACK_TIMEOUT
    if r == ACK_SUCCESS and IsMasterUser(g_rx_buf[4]) == TRUE:
        latest_scanned_id = g_rx_buf[3]
        publish(myChannel, {"finger_scanner": latest_scanned_id})
        time.sleep(4)
        return ACK_SUCCESS
    elif g_rx_buf[4] == ACK_NO_USER:
        return ACK_NO_USER
    elif g_rx_buf[4] == ACK_TIMEOUT:
        return ACK_TIMEOUT
    else:
        return ACK_GO_OUT  # The center of the fingerprint is out of alignment with sensor


# ***************************************************************************
# @brief    Analysis the command from PC terminal
# ***************************************************************************/
def Analysis_PC_Command(command):
    global Finger_SleepFlag

    if command == "CMD1" and Finger_SleepFlag != 1:
        print("Number of fingerprints already available:  %d" % GetUserCount())
    elif command == "CMD2" and Finger_SleepFlag != 1:
        print("Add fingerprint  (Put your finger on sensor until successfully/failed information returned) ")
        r = AddUser()
        if r == ACK_SUCCESS:
            print("Fingerprint added successfully !")
        elif r == ACK_FAIL:
            print(
                "Failed: Please try to place the center of the fingerprint flat to sensor, or this fingerprint already exists !")
        elif r == ACK_FULL:
            print("Failed: The fingerprint library is full !")
            Analysis_PC_Command("CMD5")
    elif command == "CMD3" and Finger_SleepFlag != 1:
        print("Waiting Finger......Please try to place the center of the fingerprint flat to sensor !")
        r = VerifyUser()
        if r == ACK_SUCCESS:
            print("Matching successful !")
        elif r == ACK_NO_USER:
            print("Failed: This fingerprint was not found in the library !")
        elif r == ACK_TIMEOUT:
            print("Failed: Time out !")
        elif r == ACK_GO_OUT:
            print("Failed: Please try to place the center of the fingerprint flat to sensor !")
    elif command == "CMD4" and Finger_SleepFlag != 1:
        ClearAllUser()
        print("All fingerprints have been cleared !")
    elif command == "CMD5" and Finger_SleepFlag != 1:
        GPIO.output(Finger_RST_Pin, GPIO.LOW)
        Finger_SleepFlag = 1
        print(
            "Module has entered sleep mode: you can use the finger Automatic wake-up function, in this mode, only CMD6 is valid, send CMD6 to pull up the RST pin of module, so that the module exits sleep !")
    elif command == "CMD6":
        Finger_SleepFlag = 0
        GPIO.output(Finger_RST_Pin, GPIO.HIGH)
        print("The module is awake. All commands are valid !")
    else:
        print("commands are invalid !")


# ***************************************************************************
# @brief   If you enter the sleep mode, then open the Automatic wake-up function of the finger,
#         begin to check if the finger is pressed, and then start the module and match
# ***************************************************************************/
def Auto_Verify_Finger():
    while True:
        # print("INSIDE")
        # time.sleep(3)
        if Finger_SleepFlag == 1:
            if GPIO.input(Finger_WAKE_Pin) == 1:  # If you press your finger
                time.sleep(0.01)
                if GPIO.input(Finger_WAKE_Pin) == 1:
                    GPIO.output(Finger_RST_Pin,
                                GPIO.HIGH)  # Pull up the RST to start the module and start matching the fingers
                    time.sleep(0.25)  # Wait for module to start
                    print("Waiting Finger......Please try to place the center of the fingerprint flat to sensor !")
                    r = VerifyUser()
                    if r == ACK_SUCCESS:
                        print("Matching successful !")
                        # Finger_SleepFlag = 1
                        # break
                    elif r == ACK_NO_USER:
                        print("Failed: This fingerprint was not found in the library !")
                    elif r == ACK_TIMEOUT:
                        print("Failed: Time out !")
                    elif r == ACK_GO_OUT:
                        print("Failed: Please try to place the center of the fingerprint flat to sensor !")

                    # After the matching action is completed, drag RST down to sleep
                    # and continue to wait for your fingers to press
                    GPIO.output(Finger_RST_Pin, GPIO.LOW)
        time.sleep(0.2)


def main():
    GPIO.output(Finger_RST_Pin, GPIO.LOW)
    time.sleep(0.25)
    GPIO.output(Finger_RST_Pin, GPIO.HIGH)
    time.sleep(0.25)  # Wait for module to start
    while SetCompareLevel(5) != 5:
        print(
            "***ERROR***: Please ensure that the module power supply is 3.3V or 5V, the serial line connection is correct.")
    time.sleep(1)
    print("OUTSIDE LOOP OF DEATH")
    print("***************************** WaveShare Capacitive Fingerprint Reader Test *****************************")
    print("Compare Level:  5    (can be set to 0-9, the bigger, the stricter)")
    print("Number of fingerprints already available:  %d " % GetUserCount())
    print(" send commands to operate the module: ")
    print("  CMD1 : Query the number of existing fingerprints")
    print(
        "  CMD2 : Register fingerprint  (Put your finger on the sensor until successfully/failed information returned) ")
    print("  CMD3 : Fingerprint matching  (Send the command, put your finger on sensor) ")
    print("  CMD4 : Clear fingerprints ")
    print(
        "  CMD5 : Switch to sleep mode, you can use the finger Automatic wake-up function (In this state, only CMD6 is valid. When a finger is placed on the sensor,the module is awakened and the finger is matched, without sending commands to match each time. The CMD6 can be used to wake up) ")
    print("  CMD6 : Wake up and make all commands valid ")
    print("***************************** WaveShare Capacitive Fingerprint Reader Test ***************************** ")

    t = threading.Thread(target=Auto_Verify_Finger)
    t.daemon = True
    t.start()

    global latest_scanned_id

    # while True:
    #     print("Latest Scanned ID: ", latest_scanned_id)
    #     str = input("Please input command (CMD1-CMD6):")
    #     Analysis_PC_Command(str)
    # def run_it():
    #     Analysis_PC_Command("CMD5")

    Analysis_PC_Command("CMD5")

    # Analysis_PC_Command("CMD3")


class SubscribeHandler(SubscribeCallback):
    def message(self, pubnub, message):
        print("Message payload: %s" % message.message)
        print("Message publisher: %s" % message.publisher)

        msg = message.message

        #if message.publisher == "serverJS":
            #print(message.message['description'])

        key = list(msg.keys())
        if key[0] == "title":

            if message.message['title'] == "Command":
                Analysis_PC_Command("CMD6")
                time.sleep(1)
                Analysis_PC_Command(message.message['description'])
                    ##time.sleep(2)
        #Analysis_PC_Command("CMD5")
        # msg = message.message
        # time.sleep(2)
        # Analysis_PC_Command("CMD5")

        # key = list(msg.keys())
        # if key[0] == "Account":
        # print("Account matched")
        ##start facial recognition


# pubnub
def publish(custom_channel, msg):
    pubnub.publish().channel(custom_channel).message(msg).pn_async(my_publish_callback)


def my_publish_callback(envelope, status):
    # Check whether request successfully completed or not
    if not status.is_error():
        pass  # Message successfully published to specified channel.
    else:
        pass  # Handle message publish error. Check 'category' property to find out possible issue
        # because of which request did fail.
        # Request can be resent using: [status retry];


class MySubscribeCallback(SubscribeCallback):
    def presence(self, pubnub, presence):
        pass  # handle incoming presence data

    def status(self, pubnub, status):
        if status.category == PNStatusCategory.PNUnexpectedDisconnectCategory:
            pass  # This event happens when radio / connectivity is lost

        elif status.category == PNStatusCategory.PNConnectedCategory:
            # Connect event. You can do stuff like publish, and know you'll get it.
            # Or just use the connected event to confirm you are subscribed for
            # UI / internal notifications, etc
            pubnub.publish().channel(myChannel).message('Connected to PubNub').pn_async(my_publish_callback)
        elif status.category == PNStatusCategory.PNReconnectedCategory:
            pass
            # Happens as part of our regular operation. This event happens when
            # radio / connectivity is lost, then regained.
        elif status.category == PNStatusCategory.PNDecryptionErrorCategory:
            pass
            # Handle message decryption error. Probably client configured to
            # encrypt messages and on live data feed it received plain text.

    def message(self, pubnub, message):
        # Handle new message stored in message.message
        try:
            print(message.message)
            msg = message.message
            key = list(msg.keys())
            if key[0] == "event":  # {"event" : {"sensor_name" : True}}
                self.handleEvent(msg)
        except Exception as e:
            print("Received: ", message.message)
            print(e)
            pass

    def handleEvent(self, msg):
        global data
        eventData = msg["event"]
        key = list(eventData.keys())
        if key[0] in sensorList:
            if eventData[key[0]] is True:
                data["alarm"] = True
            elif eventData[key[0]] is False:
                data["alarm"] = False


if __name__ == '__main__':
    try:
        main()
        # pubnub.add_listener(main())
        pubnub.add_listener(SubscribeHandler())
        pubnub.subscribe().channels(myChannel).execute()

    except KeyboardInterrupt:
        if ser != None:
            ser.close()
        GPIO.cleanup()
        print("\n\n Test finished ! \n")
        sys.exit()

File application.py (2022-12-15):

import os
import socket
import time

from dateutil.utils import today
from flask import Flask, redirect, render_template, request, session
from flask_session import Session
from flask_mysqldb import MySQL
from werkzeug.utils import secure_filename
import bcrypt

import datetime
from pubnub.callbacks import SubscribeCallback
from pubnub.enums import PNStatusCategory, PNOperationType
from pubnub.pnconfiguration import PNConfiguration
from pubnub.pubnub import PubNub
from datetime import datetime
from dotenv import load_dotenv

load_dotenv()


app = Flask(__name__)
app.config['SECRET_KEY'] = 'super_secret_key'
app.config["SESSION_FILE_DIR"] = 'var/www/FlaskApp/FlaskApp/FlaskSession'

app.config["SESSION_PERMANENT"] = False
app.config["SESSION_TYPE"] = "filesystem"
app.secret_key = "superSecret"

app.config['MYSQL_HOST'] = os.getenv("MYSQL_HOST")
app.config['MYSQL_USER'] = os.getenv("MYSQL_USER")

app.config['MYSQL_PASSWORD'] = os.getenv("MYSQL_PASSWORD")
app.config['MYSQL_DB'] = os.getenv('MYSQL_DB')

app.config['UPLOAD_FOLDER'] = 'static/images/'
app.config['ALLOWED_EXTENSIONS'] = {'txt', 'pdf', 'png', 'jpg', 'jpeg', 'gif'}

# PUBNUB
myChannel = "dmn-channel"
sensorList = ["finger_scanner, finger_scanner_new"]
data = {}

pnconfig = PNConfiguration()

pnconfig.subscribe_key = os.getenv("SUBSCRIBE_KEY")
pnconfig.publish_key = os.getenv("PUBLISH_KEY")
#pnconfig.uuid = 'webserver'
pnconfig.uuid = 'exterior-pi'

pubnub = PubNub(pnconfig)

#pubnub.subscribe() \
    #.channels(myChannel) \
    #.execute()


# mysql app
mysql = MySQL(app)
# flask session
Session(app)


def publish(custom_channel, msg):
    pubnub.publish().channel(custom_channel).message(msg).pn_async(my_publish_callback)


def my_publish_callback(envelope, status):
    # Check whether request successfully completed or not
    if not status.is_error():
        pass  # Message successfully published to specified channel.
    else:
        print("not published")
        print(status)
        print(status.is_error())
        pass  # Handle message publish error. Check 'category' property to find out possible issue
        # because of which request did fail.
        # Request can be resent using: [status retry];


class MySubscribeCallback(SubscribeCallback):
    def presence(self, pubnub, presence):
        pass  # handle incoming presence data

    def status(self, pubnub, status):
        if status.category == PNStatusCategory.PNUnexpectedDisconnectCategory:
            pass  # This event happens when radio / connectivity is lost

        elif status.category == PNStatusCategory.PNConnectedCategory:
            # Connect event. You can do stuff like publish, and know you'll get it.
            # Or just use the connected event to confirm you are subscribed for
            # UI / internal notifications, etc
            pubnub.publish().channel(myChannel).message({"Connection": "Connected to PubNub"}).pn_async(
                my_publish_callback)
        elif status.category == PNStatusCategory.PNReconnectedCategory:
            pass
            # Happens as part of our regular operation. This event happens when
            # radio / connectivity is lost, then regained.
        elif status.category == PNStatusCategory.PNDecryptionErrorCategory:
            pass
            # Handle message decryption error. Probably client configured to
            # encrypt messages and on live data feed it received plain text.

    def message(self, pubnub, message):
        print("Message payload: %s" % message.message)
        print("Message publisher: %s" % message.publisher)
        msg = message.message

        with app.app_context():
            key = list(msg.keys())
            if key[0] == "finger_scanner":
                cur = mysql.connection.cursor()
                fingerID = str(message.message['finger_scanner'])
                print("FINGERID : ",fingerID)
                cur.execute(''' SELECT employee_id, employee_firstname, employee_surname FROM employee_table where fingerprint_id = {0}'''.format(fingerID))
                account = cur.fetchone()
                if account:
                    print(account[0])
                    currentDay = today()
                    currentTime = datetime.now().time()
                    print(message.message['finger_scanner'])
                    cur.execute(''' INSERT INTO employee_access_table VALUES(null,%s,%s,%s)''',
                            (currentDay, currentTime, account[0]))




                    accDetails = {"id": account[0], "firstName": account[1], "secondName": account[2]}
                    print(accDetails)
                    publish(myChannel, {"Account": accDetails})
                mysql.connection.commit()
                cur.close()
            elif key[0] == "finger_scanner_new":
                print("new finger Scanned")
                time.sleep(2)
                publish(myChannel, {'title': 'Command', 'description': 'CMD5'})
            elif key[0] == "finger_prints_removed":
                print("fingerprints removed")
                time.sleep(3)
                publish(myChannel, {'title': 'Command', 'description': 'CMD5'})
            else:
                print("Neither scan nor match")


pubnub.add_listener(MySubscribeCallback())


@app.route("/")
def index():
    if not session.get("email"):
        return redirect("/login")
    cursor = mysql.connection.cursor()
    cursor.execute(''' SELECT * FROM employee_table''')
    employees = cursor.fetchall()

    cursor.execute(''' SELECT DISTINCT ac.access_id, emp.employee_firstname, ac.employee_access_date, ac.employee_access_time FROM employee_access_table ac, employee_table emp WHERE ac.employee_id = emp.employee_id;
''')

    log = cursor.fetchall()
    cursor.close()

    encoded = []
    for row in employees:
        write_file(row[4].to_bytes(2, 'big'), app.config['UPLOAD_FOLDER'] + str(row[5]))

    return render_template("index.html", employees=employees, log=log)
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

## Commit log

2022-10-07 Testing Word and Doc Track Changes
2022-10-08 Add hardware section to document
    Fritzing circuit diagram, diagram commentary, current problems and
    currently understood hardware needs added to hardware section of the
    document.
2022-10-09 Update hardware section in document
    Fritzing circuit diagram updated, diagram commentary expanded to deal
    with new problems and solved problems were removed.
2022-10-09 Add PIR sensor and better labels to diagram
2022-10-14 Add Fritzing file and imported modules
    [DMN_Version_1.5.fzz, Untitled Sketch 4.fzz]
2022-10-14 Added secondary raspberry pi and wiring + components
    [DMN_Version_1.5.fzz]
2022-10-14 Moved Lock to interior pi, added lcd screen
    [DMN_Version_1.5.fzz]
2022-10-14 fixed missing text for lock
    [DMN_Version_1.5.fzz]
2022-10-14 Add user flowcharts to document
2022-10-20 Added Flask Prototype, target and success criteria
2022-10-20 Update README.md
    QR for our website prototype
2022-10-22 Added LCD display pinouts, updated frizting
    [DMN_Version_1.5.fzz]
2022-11-10 Add a Trigger that inserts data into the face_table and finger_table after it has been inserted into the employee table
2022-11-11 :sparkles: Core fingerprint code
2022-11-11 :SPARKLES: (Michaels Commit, due to pip issues I am using nathans laptop to push) Admin table server work
    [application.py]
2022-11-11 :white_check_mark: (Michaels Commit part 2, due to pip issues I am using nathans laptop to push) With help from Nathan 1, Created a register Admin table in the database and html page that creates the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
    [application.py]
2022-11-14 :bug: Fingerprint sample code to start with
    [fingerprint.py, fingerprintMk2.py]
2022-11-16 trace bug to serial write() OR serial in_waiting
    The original code did not work due to deprecated python methods and
    deprecated external library methods. The bug currently resides
    either on line 91 or 99. between 1/4 and 1/3 of the code has been
    checked for deprecated code. DO NOT TOUCH THIS FILE LET ME FINISH!!!
    [fingerprint.py]
2022-11-16 :sparkles: Michaels V3, Added barebones to display an employee table :bug: data not displaying
    [application.py]
2022-11-16 :sparkles: fixed the insert query on the employee table where face and finger where mixed up :sparkles: Updated the database so the image is stored as a BLOB type
    [application.py]
2022-11-16 :sparkles: Edit for the employee route, :bug: can save as a blob filetype but can't read it yet
    [application.py]
2022-11-16 :bug: Display employee images but must be locally saved to work
    [application.py]
2022-11-17 add proof that the finger scanner legitimately works
    what prevented this in original code: deprecated methods,
    python utf-8 to byte encoding not meshing with the encoding
    needed for the scanner, tx and rx pins being swapped in documentation.
    [first_working_fingerprint_command.py]
2022-11-17 :ambulance: Fixed display employees images
    [application.py]
2022-11-17 :ambulance: Fixed the edit issues:beer:
    [application.py]
2022-11-17 :ambulance: fix the issue with fingerprint by editing the employee table by dropping it, fixed the code on the clientside and application.py that go with it
    [application.py]
2022-11-17 :ambulance: fix the issue that was a result of my previous commit that broke the edit, it has now been resoloved
    [application.py]
2022-11-18 :ambulance: Fix bugs from original fingerprint example code
    After much research and trial/error, representing hex commands as
    Integer values, processing integers for checksums, and using pythons
    integer to byte encoding ended up being the best way to go about fixing
    bugs in the original code example.
    At first, I thought python encoding certain integers as characters,
    e.g. 0 becomes b'\x00' BUT 9 becomes b'\t', was throwing off the
    format of my data packets which get sent to the finger scanner, and
    the scanner was rejecting these characters expecting to see hex
    values, but this was not the case.
    The real culprit was unicode being encoded to hex, giving more bytes
    than allowed per packet, an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
    [fingerprintMk2.py]
2022-11-19 🎨 Added absolute art
2022-11-19 🎨 More Changes
2022-11-19 :sparkles: Added camera livestream
2022-11-21 Add fingerprint posting to pubnub on scan and on finger addition
2022-11-21 :memo: Modifications to the database update query that sets the fingerprint
2022-11-21 :memo: Modifications to the database update query that sets the fingerprint also made small changes to the forms which hides the password
2022-11-21 :ambulance: fixed log query statement, fixed endfor loop
    [application.py]
2022-11-21 start of powerpoint
2022-11-21 🎨 Yassified it
2022-11-21 :ambulance: publish log to db(need michael to fix fk dependency
    [application.py]
2022-11-22 🎨 Near Finished CSS
2022-11-22 :memo: Added a query to allow for the log fingerprint to display name and time accessed
2022-11-22 :beer: Updated routes to pass the fingerscanner data through:beer: :sparkles: added a new query that joins the employee_table and the employee_access_table:memo:
2022-11-23 :ambulance: Minor update to the delete query on the application that fixes the error : not all arguments converted during bytes formatting
    [application.py]
2022-11-23 :ambulance: Further fixes on the delete queries added a new one that removes the employee from the access table (constraint issue)
    [application.py]
2022-12-01 :ambulance: first-time run fixes, restructured sql statements, test logo folder upload
    [application.py]
2022-12-04 :sparkles: Register Fingerprint directly to employee :ambulance: updated publishernames :sparkles: pubnubJS dependencies :sparkles: fingerprint commands from website
2022-12-06 :sparkles: Register Fingerprint when adding employee, publish base64encoded employee image for facial recog :ambulance: fixed log query(again) :sparkles: added image in edit employee :sparkles: clear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
    [application.py, fingerprintMk2.py, pb.py]
2022-12-07 :bug: fixed the edit but the image uploads for everyone
    [application.py]
2022-12-07 :bug: need to sort out the edit where you have to constantly read in a new image file, even if one already exists in the database
    [application.py]
2022-12-07 add successful image transmission through socket
2022-12-08 :ambulance: fixed edit image
    [application.py]
2022-12-08 :ambulance: database fixes, and added views
    [application.py]
2022-12-11 Files functioning and working in unison
    application.py must be run first (currently locally), then FingerprintFin & DisplayFin.py shall be
    started, in that order, on the raspberry pi connected to the fingerprint sensor and display, and
    they shall be started on the display itself, not through putty or remote desktop, lastly,
    LockSwitch.py should be started on the second pi which is connected to the lock.
2022-12-12 :art: Added Footer and made changes to Button placement
2022-12-13 :art: Added FingerPrint log for particular employee
2022-12-13 🔐 Added Validation to Password and Validation to add Employee
2022-12-15 Add last minute bug-fixes
    fingerprint doesn't get caught up after pubnub issued commands anymore.
    [DisplayFin.py, application.py, fingerprintFin.py]
